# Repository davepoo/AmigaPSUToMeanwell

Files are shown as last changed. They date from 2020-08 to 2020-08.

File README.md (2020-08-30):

# Amiga PSU To Meanwell
KiCad design for a PCB for a board to mount a Meanwell RT50-B PSU inside an external Amiga PSU A300/600 case.

# Known case compatibility:
A300/600 Power Supply - P-No: 391029-02

Its possible that this design also works in the A1200 PSU but i don't have one to verify that.

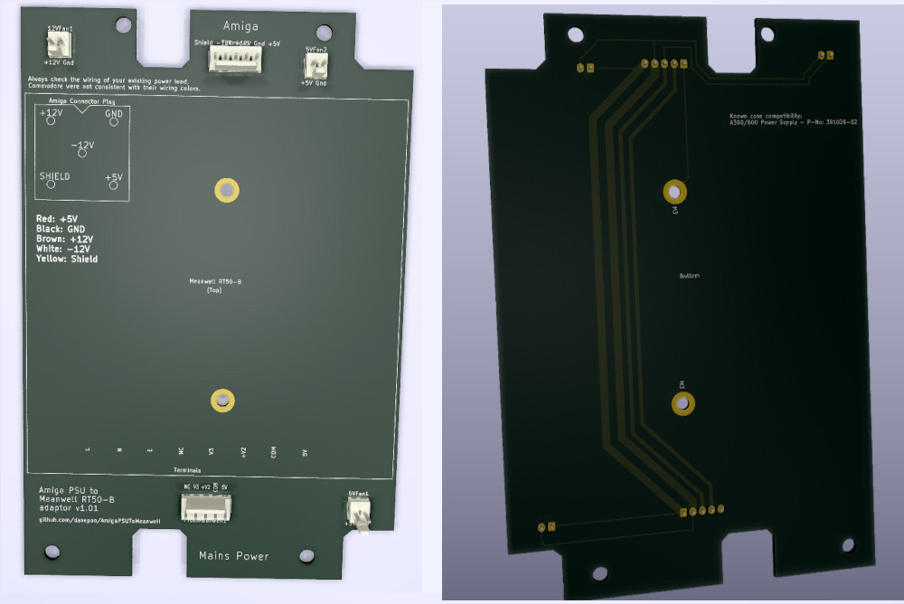
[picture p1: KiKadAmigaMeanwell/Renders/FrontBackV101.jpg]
Picture of front of PCB


# A600 PSU Variants

There are 5 variants of the A600 PSU listed in the service manual, I have only tested the -02 variant (UK Plug), but i would imagine that all these other variants are mechanically the same, so would probably work just as well with this adaptor

A600 Service Manual

PSU Part numbers:

* 391329-01
* 391329-02 - UK Plug (240V)
* 391329-03
* 391329-04
* 391329-05

# A500+ PSU possibly is compatible?

From visual appearances (i don't have one to look at in person), it is possible the A500+ PSU might be mechancially identical to the A600 PSU and therefore might also be compatible with this PCB.

A500+ Service Manual

PSU Part numbers:

* 321503-01
* 321503-02 - UK Plug (240V)
* 321503-03
* 321503-04
* 321503-05

# Parts
The PCB was designed for these connecters, by any suitable 2.54mm pitch connectors will do the job.

* Molex, KK 254, 6410, 2 Way, 1 Row, Straight PCB Header - https://uk.rs-online.com/web/p/pcb-headers/4838461/
* Molex, KK 254, 6410, 5 Way, 1 Row, Straight PCB Header - https://uk.rs-online.com/web/p/pcb-headers/1707104/

# YouTube
* v1.01 Assembly - https://youtu.be/UummiZiRQis
* v1.01 Changes - https://youtu.be/RRZ41WjXUbk
* Design in KiCad - https://youtu.be/qDFmNK3edf4

# PCBWay 
The v1.01 board is shared on PCBWay where i got the prototypes manufactured 

https://www.pcbway.com/project/shareproject/A600_PSU_to_Meanwell_RT50_B_Adaptor_board.html

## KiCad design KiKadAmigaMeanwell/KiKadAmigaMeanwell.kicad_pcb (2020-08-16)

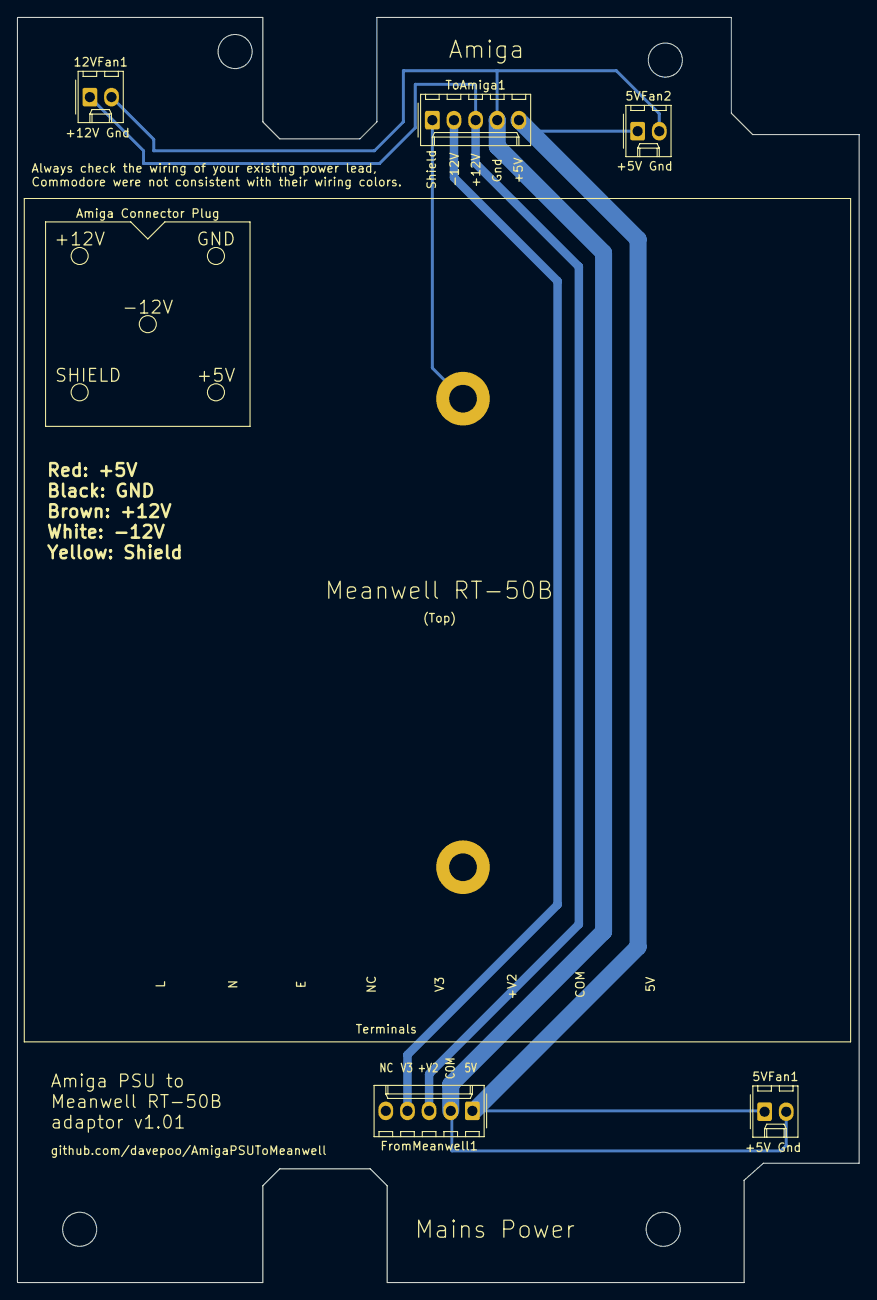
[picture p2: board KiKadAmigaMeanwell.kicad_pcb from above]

Board: 2 copper layers, 98.8 x 148.5 mm, 11 parts (0 on the bottom side), 4 nets.

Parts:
5VFan1, 5VFan2, 12VFan1: Conn_01x02; Molex_KK-254_AE-6410-02A_1x02_P2.54mm_Vertical
Amiga Connector Plug: AmigaConnector
FromMeanwell1: Conn_01x05; Molex_KK-254_AE-6410-05A_1x05_P2.54mm_Vertical
Meanwell RT-50B: Meanwell_RT50-B
Screw: MountingHole_4mm
Screw#2, Screw#3, Screw#4: MountingHole_4mm
ToAmiga1: Conn_01x05; Molex_KK-254_AE-6410-05A_1x05_P2.54mm_Vertical

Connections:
+5V: 5VFan1.1, 5VFan2.1, FromMeanwell1.1, ToAmiga1.5
+12V: 12VFan1.1, FromMeanwell1.3, ToAmiga1.3
-12V: FromMeanwell1.4, ToAmiga1.2
GND: 5VFan1.2, 5VFan2.2, 12VFan1.2, FromMeanwell1.2, ToAmiga1.4

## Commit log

2020-08-06 - adding KiCad files and Gerbers for v1.00
    [KiKadAmigaMeanwell-B_Cu.gbr, KiKadAmigaMeanwell-B_Mask.gbr, KiKadAmigaMeanwell-B_Paste.gbr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]
2020-08-14 - changing out the connectors to Molex KK 5 pin connectors / adding 5V/12V fan headers (not connected yet)
    [KiKadAmigaMeanwell.kicad_pcb]
2020-08-14 - adding schematic, and routing the tracks for the connectors and fan headers on the PCB
    [KiKadAmigaMeanwell.kicad_pcb, KiKadAmigaMeanwell.sch]
2020-08-15 - connecting the shield pin to earth instead of ground, making smaller trace widths for the fan headers (0.5A)
    [KiKadAmigaMeanwell.kicad_pcb, KiKadAmigaMeanwell.sch]
2020-08-15 - adding a second 5V fan header
    [KiKadAmigaMeanwell.kicad_pcb, KiKadAmigaMeanwell.sch]
2020-08-15 - adjusting edge cuts to fit around the plastic standoffs
    [KiKadAmigaMeanwell.kicad_pcb]
2020-08-15 - adding voltage and ground silkscreen to the fan headers
    [KiKadAmigaMeanwell.kicad_pcb]
2020-08-16 - taking 0.2mm off the left hand edge cut & correcting silkscreen errors
    [KiKadAmigaMeanwell.kicad_pcb]
2020-08-16 - Gerber files for v1.01
    [KiKadAmigaMeanwell-B_Cu.gbr, KiKadAmigaMeanwell-B_Mask.gbr, KiKadAmigaMeanwell-B_Paste.gbr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]
2020-08-29 PCBWay project links
